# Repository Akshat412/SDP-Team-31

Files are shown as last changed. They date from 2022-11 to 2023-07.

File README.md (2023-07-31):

# SDP-Team-31
SDP23 Project for Team 31

We present SMH, a smart biking helmet and associated sensing system which can sense riders’ vital signs such as heart rate, ambient temperature and humidity, and make it accessible to them while they bike. In the event of an accident, the system would send a remote alert to a registered contact, including the rider’s location. The helmet uses a microcontroller for sampling a MEMS accelerometer capable of measuring upto 200 Gs of acceleration at 4 KHz for collision detection. In the event of a dangerous collision, the system communicates with an Android app over Bluetooth Low Energy, which then sends a text message to an emergency contact. The bike board samples temperature, humidity, heart rate, altitude and UV-index and displays them to the biker during their bike ride. Both devices are lightweight, inexpensive, and have long battery lives. 

Members: 
Marloon Paula Gonzalez - EE 2023; 
Max Morel - EE 2023; 
Ruchit Patel - EE 2023; 
Akshat Sahay - CompE 2023; 

This repository contains the hardware and software for the helmet board which performs concussion detection and generates BLE alerts for the associated smartphone app in case of a dangerous collision. Software is written using the RP2040 core in Arduino, with the Adafruit BLE Friend library to interface with the BLE module. The hardware is designed in KiCad 7.

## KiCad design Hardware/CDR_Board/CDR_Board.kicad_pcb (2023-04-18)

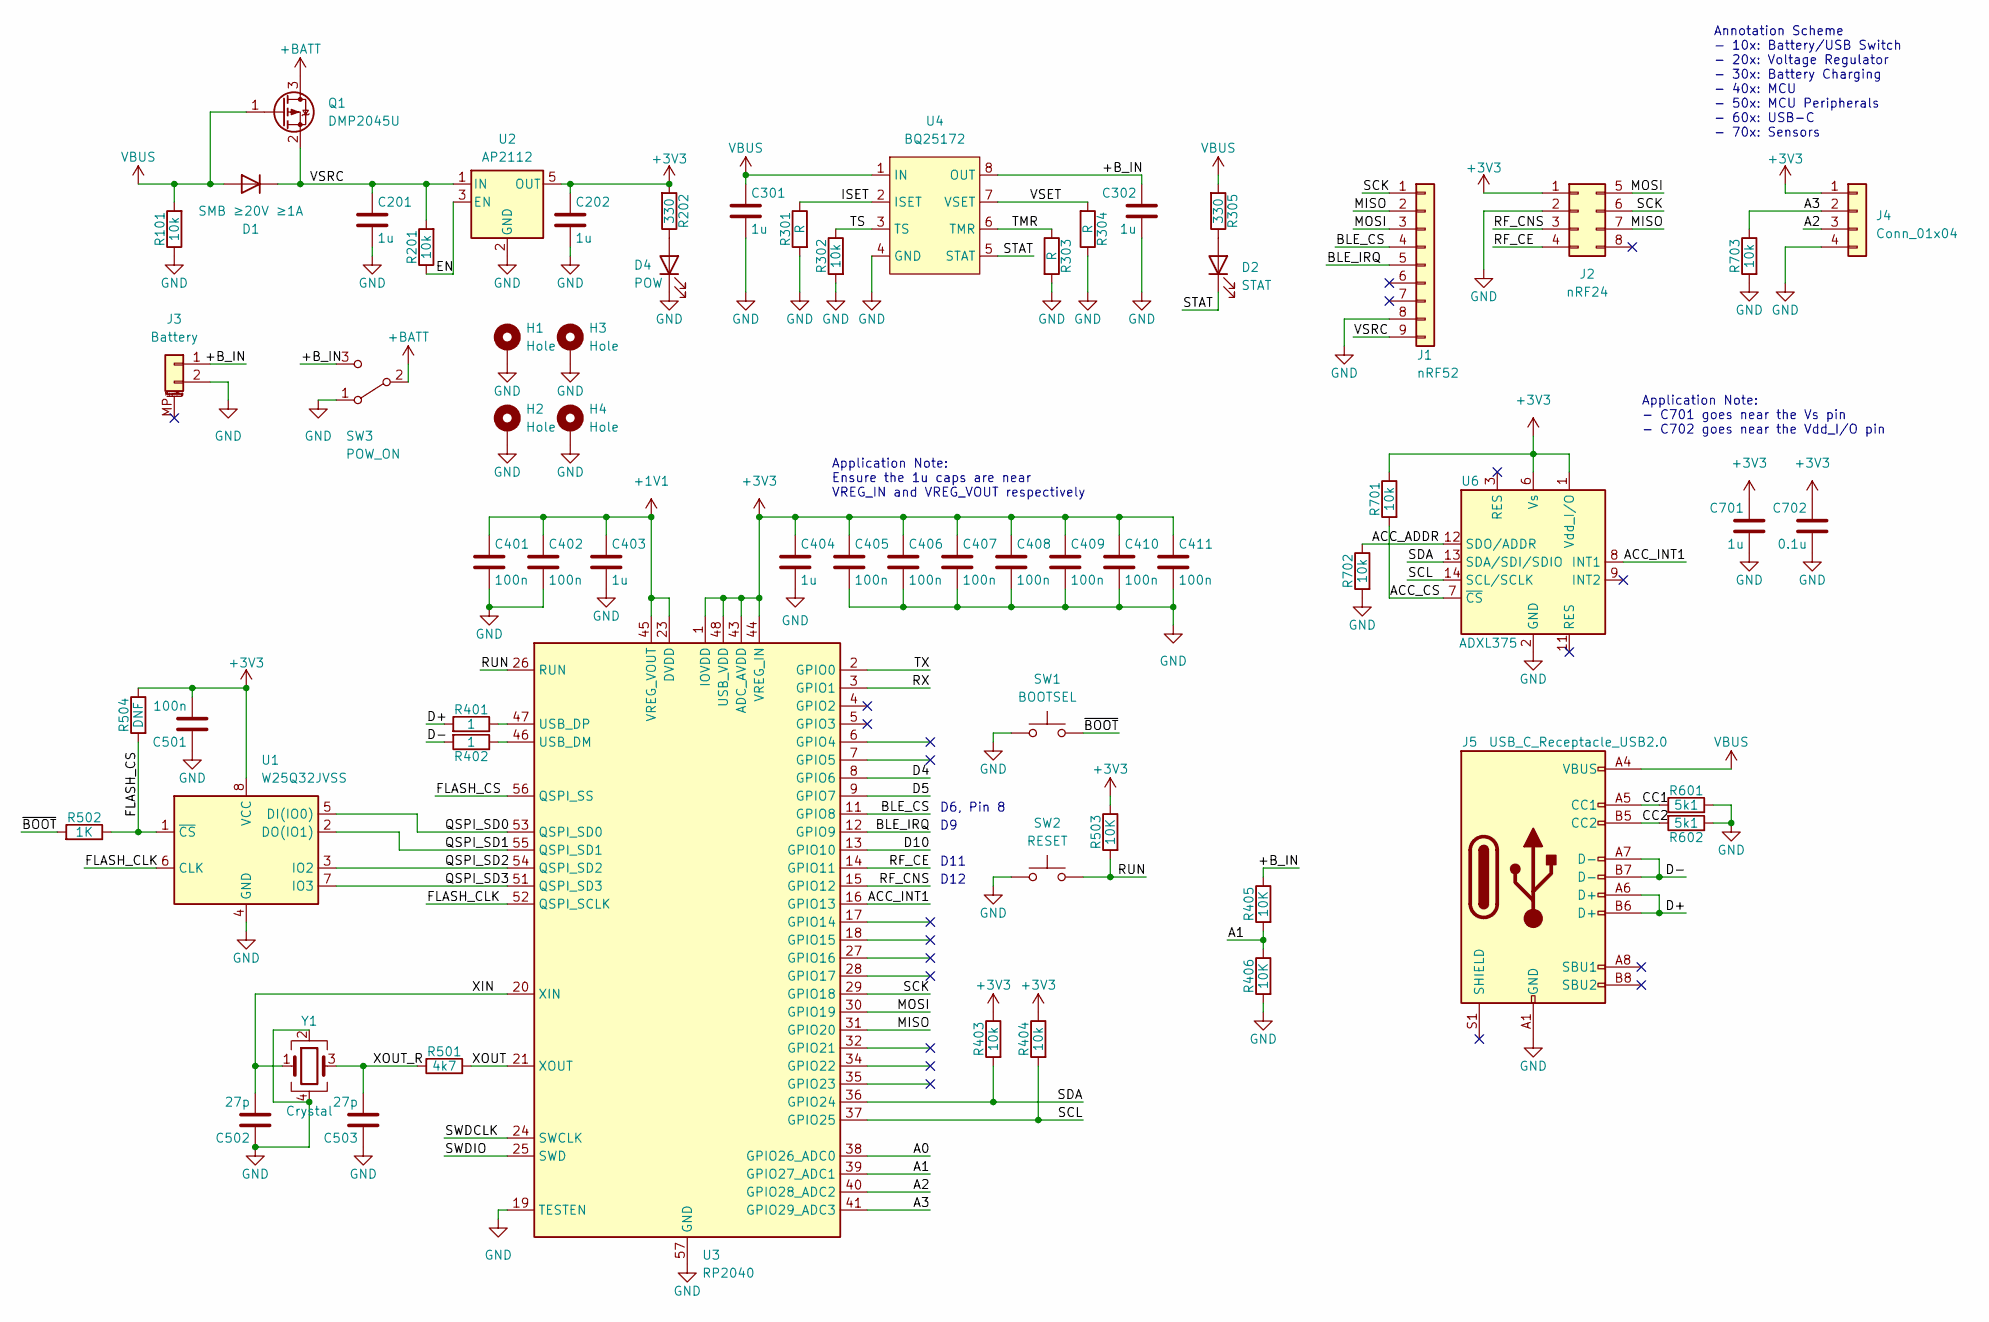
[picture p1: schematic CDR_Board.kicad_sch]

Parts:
C201, C202, C301, C302, C701: 1u; C_0805_2012Metric_Pad1.18x1.45mm_HandSolder
C401, C402, C405, C406, C407, C408, C409, C410, C411: 100n; C_0603_1608Metric_Pad1.08x0.95mm_HandSolder
C403, C404: 1u; C_0603_1608Metric_Pad1.08x0.95mm_HandSolder
C501: 100n; C_0805_2012Metric_Pad1.18x1.45mm_HandSolder
C502, C503: 27p; C_0805_2012Metric_Pad1.18x1.45mm_HandSolder
C702: 0.1u; C_0805_2012Metric_Pad1.18x1.45mm_HandSolder
D1: SMB ≥20V ≥1A; D_SOD-323_HandSoldering
D2: STAT; LED_0805_2012Metric_Pad1.15x1.40mm_HandSolder
D4: POW; LED_0805_2012Metric_Pad1.15x1.40mm_HandSolder
H1, H2, H3, H4: Hole; MountingHole_2.2mm_M2_DIN965_Pad
J1: nRF52; PinSocket_1x09_P2.54mm_Vertical
J2: nRF24; PinSocket_2x04_P2.54mm_Vertical
J3: Battery; JST_PH_S2B-PH-SM4-TB_1x02-1MP_P2.00mm_Horizontal
J4: Conn_01x04; PinSocket_1x04_P2.54mm_Vertical
J5: USB_C_Receptacle_USB2.0; USB_C_Receptacle_Palconn_UTC16-G
Q1: DMP2045U; SOT-23
R101, R201, R302, R403, R404, R701, R702, R703: 10k; R_0805_2012Metric_Pad1.20x1.40mm_HandSolder
R202, R305: 330; R_0805_2012Metric_Pad1.20x1.40mm_HandSolder
R301, R303, R304: R; R_0805_2012Metric_Pad1.20x1.40mm_HandSolder
R401, R402: 1; R_0805_2012Metric_Pad1.20x1.40mm_HandSolder
R405, R406, R503: 10K; R_0805_2012Metric_Pad1.20x1.40mm_HandSolder
R501: 4k7; R_0805_2012Metric_Pad1.20x1.40mm_HandSolder
R502: 1K; R_0805_2012Metric_Pad1.20x1.40mm_HandSolder
R504: DNF; R_0805_2012Metric_Pad1.20x1.40mm_HandSolder
R601, R602: 5k1; R_0805_2012Metric_Pad1.20x1.40mm_HandSolder
SW1: BOOTSEL; SW_Push_1P1T_NO_CK_KMR2
SW2: RESET; SW_Push_1P1T_NO_CK_KMR2
SW3: POW_ON; E-Switch-EG1218
U1: W25Q32JVSS; SOIC-8_5.23x5.23mm_P1.27mm
U2: AP2112; SOT-23-5
U3: RP2040; QFN-56-1EP_7x7mm_P0.4mm_EP3.2x3.2mm
U4: BQ25172; WSON-8-1EP_2x2mm_P0.5mm_EP0.9x1.6mm_ThermalVias
U6: ADXL375; LGA-14_3x5mm_P0.8mm_LayoutBorder1x6y
Y1: Crystal; Crystal_SMD_SeikoEpson_FA238-4Pin_3.2x2.5mm

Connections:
+1V1: C401.1, C402.1, C403.1, U3.23 (DVDD), U3.45 (VREG_VOUT), U3.50 (DVDD)
+3V3: C202.1, C404.1, C405.1, C406.1, C407.1, C408.1, C409.1, C410.1, C411.1, C501.2, C701.1, C702.1, J2.1, J4.1, R202.2, R403.1, R404.1, R503.1, R504.1, R701.1, U1.8 (VCC), U2.5 (OUT), U3.1 (IOVDD), U3.10 (IOVDD), U3.22 (IOVDD), U3.33 (IOVDD), U3.42 (IOVDD), U3.43 (ADC_AVDD), U3.44 (VREG_IN), U3.48 (USB_VDD), U3.49 (IOVDD), U6.1 (Vdd_I/O), U6.6 (Vs)
+BATT: Q1.3 (D), SW3.2 (B)
/+B_IN: C302.1, J3.1, R405.1, SW3.3 (C), U4.8 (OUT)
/A0: U3.38 (GPIO26_ADC0)
/A1: R405.2, R406.1, U3.39 (GPIO27_ADC1)
/A2: J4.3, U3.40 (GPIO28_ADC2)
/A3: J4.2, R703.1, U3.41 (GPIO29_ADC3)
/ACC_ADDR: R702.1, U6.12 (SDO/ADDR)
/ACC_CS: R701.2, U6.7 (~CS)
/ACC_INT1: U3.16 (GPIO13), U6.8 (INT1)
/BLE_CS: J1.4, U3.11 (GPIO8)
/BLE_IRQ: J1.5, U3.12 (GPIO9)
/CC1: J5.A5 (CC1), R601.2
/CC2: J5.B5 (CC2), R602.2
/D4: U3.8 (GPIO6)
/D5: U3.9 (GPIO7)
/D10: U3.13 (GPIO10)
/D+: J5.A6 (D+), J5.B6 (D+), R401.2
/D-: J5.A7 (D-), J5.B7 (D-), R402.2
/EN: R201.1, U2.3 (EN)
/FLASH_CLK: U1.6 (CLK), U3.52 (QSPI_SCLK)
/FLASH_CS: R502.1, R504.2, U1.1 (~CS), U3.56 (QSPI_SS)
/ISET: R301.1, U4.2 (ISET)
/MISO: J1.2, J2.7, U3.31 (GPIO20)
/MOSI: J1.3, J2.5, U3.30 (GPIO19)
/QSPI_SD0: U1.5 (DI(IO0)), U3.53 (QSPI_SD0)
/QSPI_SD1: U1.2 (DO(IO1)), U3.55 (QSPI_SD1)
/QSPI_SD2: U1.3 (IO2), U3.54 (QSPI_SD2)
/QSPI_SD3: U1.7 (IO3), U3.51 (QSPI_SD3)
/RF_CE: J2.4, U3.14 (GPIO11)
/RF_CNS: J2.3, U3.15 (GPIO12)
/RUN: R503.2, SW2.2, U3.26 (RUN)
/RX: U3.3 (GPIO1)
/SCK: J1.1, J2.6, U3.29 (GPIO18)
/SCL: R404.2, U3.37 (GPIO25), U6.14 (SCL/SCLK)
/SDA: R403.2, U3.36 (GPIO24), U6.13 (SDA/SDI/SDIO)
/STAT: D2.1 (K), U4.5 (STAT)
/SWDCLK: U3.24 (SWCLK)
/SWDIO: U3.25 (SWD)
/TMR: R303.1, U4.6 (TMR)
/TS: R302.1, U4.3 (TS)
/TX: U3.2 (GPIO0)
/VSET: R304.2, U4.7 (VSET)
/VSRC: C201.1, D1.1 (K), J1.9, Q1.2 (S), R201.2, U2.1 (IN)
/XIN: C502.2, U3.20 (XIN), Y1.1
/XOUT: R501.2, U3.21 (XOUT)
/XOUT_R: C503.2, R501.1, Y1.3
/~BOOT: R502.2, SW1.2
GND: C201.2, C202.2, C301.2, C302.2, C401.2, C402.2, C403.2, C404.2, C405.2, C406.2, C407.2, C408.2, C409.2, C410.2, C411.2, C501.1, C502.1, C503.1, C701.2, C702.2, D4.1 (K), H1.1, H2.1, H3.1, H4.1, J1.8, J2.2, J3.2, J4.4, J5.A1 (GND), J5.A12 (GND), J5.B1 (GND), J5.B12 (GND), R101.1, R301.2, R302.2, R303.2, R304.1, R406.2, R601.1, R602.1, R702.2, R703.2, SW1.1, SW2.1, SW3.1 (A), U1.4 (GND), U2.2 (GND), U3.19 (TESTEN), U3.57 (GND), U4.4 (GND), U6.2 (GND), U6.4 (GND), U6.5 (GND), Y1.2, Y1.4
unnamed: D2.2 (A), R305.1
unnamed: D4.2 (A), R202.1
unnamed: R402.1, U3.46 (USB_DM)
unnamed: R401.1, U3.47 (USB_DP)
VBUS: C301.1, D1.2 (A), J5.A4 (VBUS), J5.A9 (VBUS), J5.B4 (VBUS), J5.B9 (VBUS), Q1.1 (G), R101.2, R305.2, U4.1 (IN)

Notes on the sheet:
D6, Pin 8
Annotation Scheme - 10x: Battery/USB Switch - 20x: Voltage Regulator - 30x: Battery Charging - 40x: MCU - 50x: MCU Peripherals - 60x: USB-C - 70x: Sensors
Application Note: Ensure the 1u caps are near VREG_IN and VREG_VOUT respectively
D11
Application Note: - C701 goes near the Vs pin - C702 goes near the Vdd_I/O pin
D12

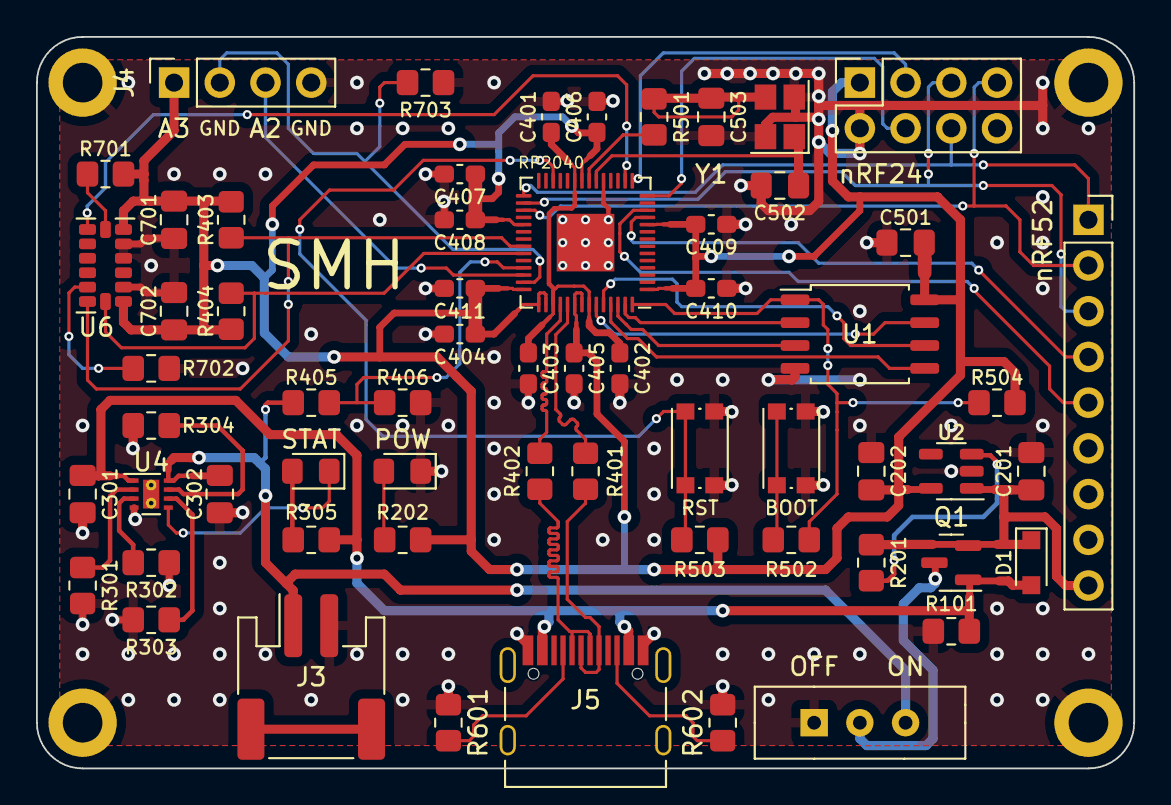
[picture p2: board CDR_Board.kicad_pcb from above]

Board: 2 copper layers, 61.0 x 40.6 mm, 65 parts (0 on the bottom side), 47 nets.

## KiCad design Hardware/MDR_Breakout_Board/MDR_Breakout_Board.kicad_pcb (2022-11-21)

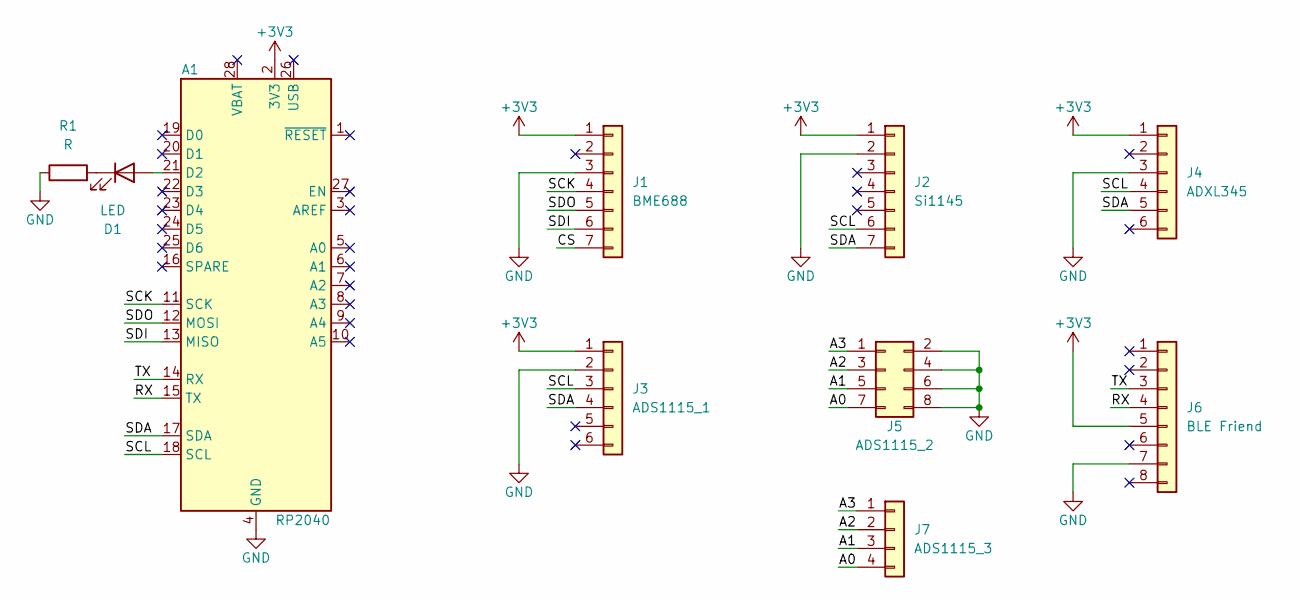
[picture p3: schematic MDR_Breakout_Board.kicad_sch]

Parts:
A1: RP2040; Adafruit_Feather
D1: LED; LED_D5.0mm
J1: BME688; PinSocket_1x07_P2.54mm_Vertical
J2: Si1145; PinSocket_1x07_P2.54mm_Vertical
J3: ADS1115_1; PinSocket_1x06_P2.54mm_Vertical
J4: ADXL345; PinSocket_1x06_P2.54mm_Vertical
J5: ADS1115_2; PinSocket_2x04_P2.54mm_Vertical
J6: BLE Friend; PinSocket_1x08_P2.54mm_Vertical
J7: ADS1115_3; PinSocket_1x04_P2.54mm_Vertical
R1: R; R_Axial_DIN0309_L9.0mm_D3.2mm_P12.70mm_Horizontal

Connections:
+3V3: A1.2 (3V3), J1.1, J2.1, J3.1, J4.1, J6.5
/A0: J5.7, J7.4
/A1: J5.5, J7.3
/A2: J5.3, J7.2
/A3: J5.1, J7.1
/CS: J1.7
/RX: A1.15 (TX), J6.4
/SCK: A1.11 (SCK), J1.4
/SCL: A1.18 (SCL), J2.6, J3.3, J4.4
/SDA: A1.17 (SDA), J2.7, J3.4, J4.5
/SDI: A1.13 (MISO), J1.6
/SDO: A1.12 (MOSI), J1.5
/TX: A1.14 (RX), J6.3
GND: A1.4 (GND), J1.3, J2.2, J3.2, J4.3, J5.2, J5.4, J5.6, J5.8, J6.7, R1.1
unnamed: A1.21 (D2), D1.2 (A)
unnamed: D1.1 (K), R1.2

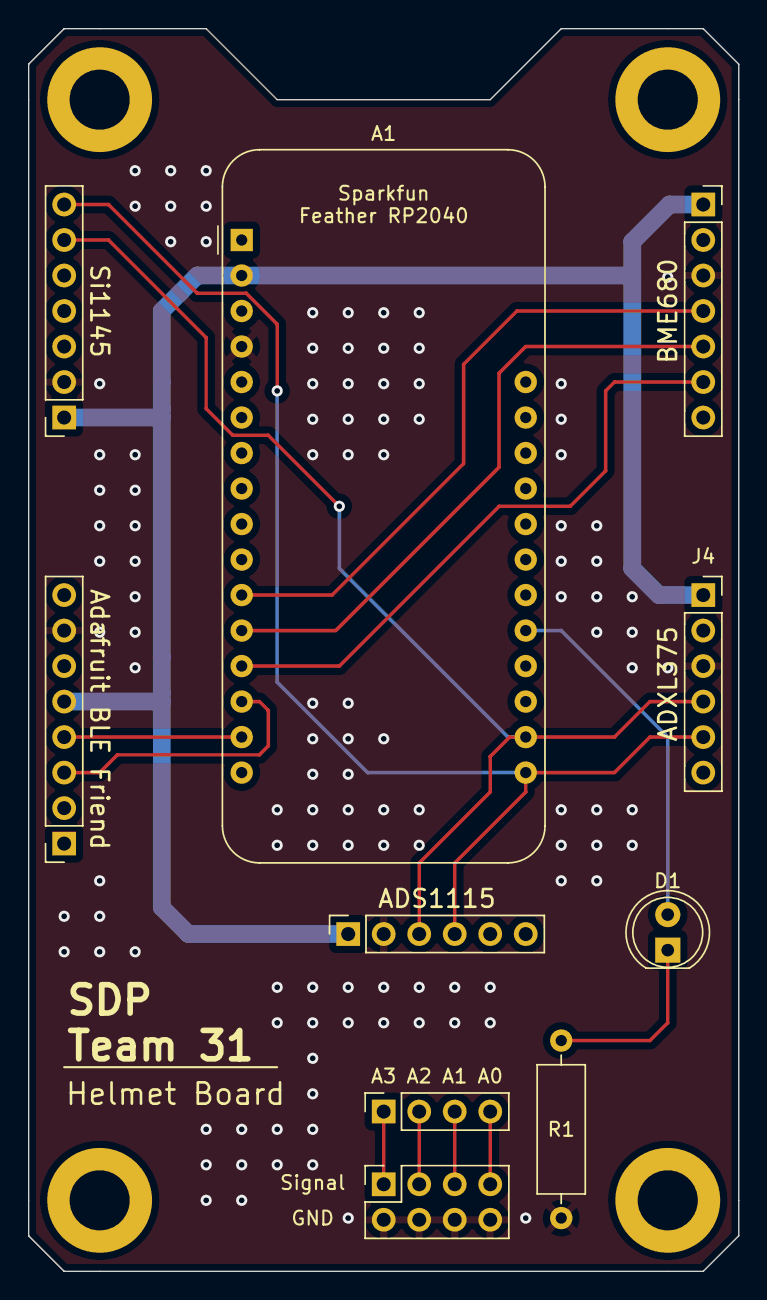
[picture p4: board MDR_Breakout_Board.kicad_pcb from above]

Board: 2 copper layers, 50.8 x 88.9 mm, 10 parts (0 on the bottom side), 15 nets.

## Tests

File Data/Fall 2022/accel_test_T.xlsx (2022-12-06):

T | M
1923 | 1.04 | 0
1926 | 0.98 | 0
1928 | 1.08 | 0
1931 | 1.16 | 0
1933 | 1.12 | 0
1935 | 0.96 | 0
1937 | 0.95 | 0
1939 | 0.9 | 0
1941 | 1.24 | 0
1943 | 0.93 | 0
1946 | 0.89 | 0
1948 | 1.16 | 0
1950 | 1.04 | 0
1952 | 0.91 | 0
1955 | 0.88 | 0
1957 | 0.89 | 0
1959 | 0.9 | 0
1961 | 0.89 | 0
1963 | 1.04 | 0
1966 | 0.9 | 0
1968 | 0.71 | 0
1970 | 1.22 | 0
1972 | 1.06 | 0
1974 | 1.03 | 0
1976 | 0.96 | 0
1979 | 1.22 | 0
1981 | 1.3 | 0
1983 | 0.71 | 0
1985 | 1.29 | 0
1987 | 1.32 | 0
1990 | 0.96 | 0
1992 | 1.11 | 0
1994 | 0.8 | 0
1996 | 1.12 | 0
1999 | 1.01 | 0
2001 | 1.06 | 0
2003 | 1 | 0
2005 | 1.01 | 0
2007 | 1.08 | 0
2010 | 0.98 | 0
2012 | 1.28 | 0
2014 | 1.14 | 0
2016 | 0.81 | 0
2018 | 1.06 | 0
2021 | 0.72 | 0
2023 | 0.79 | 0
2025 | 1.12 | 0
2027 | 1.1 | 0
2029 | 1.11 | 0
2032 | 1.21 | 0
2034 | 1 | 0
2036 | 1.08 | 0
2038 | 1.1 | 0
2040 | 1 | 0
2042 | 1.33 | 0
2045 | 1.01 | 0
2047 | 1.35 | 0
2049 | 0.86 | 0
2051 | 0.91 | 0
2053 | 0.81 | 0
2055 | 1 | 0
2057 | 1.1 | 0
2060 | 1.06 | 0
2062 | 1.04 | 0
2064 | 1 | 0
2066 | 0.93 | 0
2068 | 1.23 | 0
2071 | 0.99 | 0
2073 | 0.93 | 0
2075 | 1.2 | 0
2077 | 0.84 | 0
2079 | 1.12 | 0
2082 | 0.78 | 0
2084 | 0.89 | 0
2086 | 1.25 | 0
2088 | 0.98 | 0
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

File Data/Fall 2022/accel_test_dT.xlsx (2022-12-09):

=~=~=~=~=~=~=~=~=~=~=~= PuTTY log 2022.12.05 17:56:13 =~=~=~=~=~=~=~=~=~=~=~=
ADXL375 Accelerometer Test
dT
2.179721816
dT | M | C
2 | 1.09 | 0
3 | 0.95 | 0
2 | 1.01 | 0
2 | 1.12 | 0
2 | 1.13 | 0
2 | 1.32 | 0
3 | 0.93 | 0
2 | 0.81 | 0
2 | 1.5 | 0
2 | 1.02 | 0
2 | 0.98 | 0
2 | 1.08 | 0
2 | 1 | 0
2 | 0.81 | 0
2 | 1 | 0
3 | 1.31 | 0
2 | 1.1 | 0
2 | 0.88 | 0
2 | 1.25 | 0
2 | 1.24 | 0
3 | 0.72 | 0
2 | 0.9 | 0
2 | 1 | 0
2 | 0.97 | 0
2 | 0.99 | 0
3 | 1.24 | 0
2 | 1.04 | 0
2 | 0.98 | 0
2 | 0.9 | 0
2 | 1.12 | 0
2 | 1.07 | 0
2 | 1.19 | 0
2 | 1.32 | 0
2 | 1.23 | 0
3 | 1.27 | 0
2 | 1.23 | 0
2 | 1.1 | 0
2 | 0.93 | 0
2 | 0.89 | 0
3 | 1.28 | 0
2 | 1 | 0
2 | 0.91 | 0
2 | 1.28 | 0
2 | 1.3 | 0
2 | 1.06 | 0
2 | 1.12 | 0
2 | 1.24 | 0
2 | 1.12 | 0
3 | 1.08 | 0
2 | 1 | 0
2 | 1.03 | 0
2 | 1.28 | 0
3 | 1.06 | 0
2 | 1.18 | 0
2 | 1.36 | 0
2 | 1.13 | 0
2 | 1.18 | 0
3 | 0.79 | 0
2 | 1.18 | 0
2 | 1.1 | 0
2 | 1.13 | 0
2 | 1.04 | 0
2 | 1.18 | 0
3 | 1.22 | 0
2 | 1.13 | 0
2 | 1.4 | 0
2 | 0.97 | 0
2 | 1.27 | 0
3 | 1.18 | 0
2 | 1.05 | 0
2 | 1.03 | 0
2 | 1.09 | 0
2 | 1.24 | 0
3 | 1 | 0
2 | 1.02 | 0
2 | 1.19 | 0
2 | 1.11 | 0
2 | 1.35 | 0
3 | 1.18 | 0
2 | 1.09 | 0
2 | 0.89 | 0
2 | 1.16 | 0
3 | 0.95 | 0
2 | 1.27 | 0
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

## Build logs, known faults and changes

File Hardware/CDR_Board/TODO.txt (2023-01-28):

TODO:
	- Choose LDO IC 
		- 200 mA 3.3V, as efficient as possible
		- Choose passive values accordingly 
	- Design NiMH charging circuit
		- Datasheet has calculations
		- Choose passive values accordingly
		- Find appropriate NiMH batteries

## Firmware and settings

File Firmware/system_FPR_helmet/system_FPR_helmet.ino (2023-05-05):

/*
 * SDP23 Team 31
 * FPR System Software - Helmet 
 * --------------------
 * Samples accelerometer
 * If collision, goes into alert state
 * Remote alert over BLE to Android app 
 * Device mode:   switch between FSR and collisions  
 * System checks: LED turns on if peripherals connected 
 * System alerts: BUZZER if peripheral disconnected during operation 
 */

/* include statements */
#include <Wire.h>
#include <SPI.h>

#include "Adafruit_BLE.h"
#include "Adafruit_BluefruitLE_SPI.h"
#include "Adafruit_BluefruitLE_UART.h"

#include "BluefruitConfig.h"

/* hardware and const defines */
#define ADXL375 0x53
#define FSR     A3 
#define BUZZER  A2        
#define BATT    A1
#define LED     11

#define ADXL375_MG2G_MULTIPLIER (0.049) // 49mg per lsb
#define ADXL375_DEV_ID 0xE5             // accelerometer device ID 
#define FACTORYRESET_ENABLE 1           // reference in Adafruit test code 

// collision locations 
#define FRONT_RIGHT 1
#define FRONT_LEFT  2
#define BACK_RIGHT  3
#define BACK_LEFT   4

// buzzer frequencies
#define BUZZER_FSR  2000 
#define BUZZER_CD   1000
#define BUZZER_ERR  500 

/* BLE Friend over hardware SPI, using SCK/MOSI/MISO hardware SPI pins and then user selected CS/IRQ/RST */
Adafruit_BluefruitLE_SPI ble(BLUEFRUIT_SPI_CS, BLUEFRUIT_SPI_IRQ, BLUEFRUIT_SPI_RST); 

/* variables for computation */
uint8_t acc_addr = 0; // ADXL375 address

double mag = 0; // magnitude of collision

// coordinates for accelerometer 
float x = 0; 
float y = 0; 
float z = 0; 

// collision location 
double theta_impact = 0; 
uint8_t direction = 0; 

// device mode 
uint8_t dev_mode = 1; 

// FSR output 
uint16_t helm_tight = 0;

// LED state for sampling rate 
uint8_t led_state = 0; 

void setup() {
  // initialize serial at 115200
  Serial.begin(115200);

  // set SCL to 400KHz and begin I2C
  Wire.setClock(400000); 
  Wire.begin();

  // communicate to get ADXL375 address 
  Wire.beginTransmission(ADXL375);
  Wire.write(0x00); 
  Wire.endTransmission(false);

  Wire.requestFrom(ADXL375, 1, true);
  acc_addr = Wire.read();  

  // check ADXL375 return address
  if(acc_addr != ADXL375_DEV_ID) {
    while(1) {
      // print to console for debugging 
      Serial.println("ERROR: Failure communicating with ADXL375"); 

      tone(BUZZER, BUZZER_ERR);
      delay(250);
      noTone(BUZZER);
      delay(250);
    }
  }

  // communicate to set up ADXL375
  Wire.beginTransmission(ADXL375);
  Wire.write(0x2C); // write to BW_RATE register  
  Wire.write(0x0F); // set bits D3:D0 to 1101 for 800 Hz
  Wire.endTransmission();

  Wire.beginTransmission(ADXL375);
  Wire.write(0x2D); // write to POWER_CTL register 
  Wire.write(0x08); // set bit D3 high for measurement 
  Wire.endTransmission();

  Wire.beginTransmission(ADXL375);
  Wire.write(0x31); // write to DATA_FORMAT register
  Wire.write(0x0B); // set bits D4:D0 to 01011 for format
  Wire.endTransmission();

  // initialize BLE Friend 
  Serial.print(F("Initialising the Bluefruit LE module: "));
  if ( !ble.begin(VERBOSE_MODE) ) {
    while(1) {
      // print to console for debugging 
      Serial.println("ERROR: Failure communicating with BLE module"); 

      tone(BUZZER, BUZZER_ERR);
      delay(250);
      noTone(BUZZER);
      delay(250);
    } 
  }

  // factory reset to remove old characteristics 
  if ( FACTORYRESET_ENABLE ) {
    Serial.println(F("Performing a factory reset: "));
    if ( ! ble.factoryReset() ){
      while(1) {
        // print to console for debugging 
        Serial.println("ERROR: Failure resetting BLE module"); 

        tone(BUZZER, BUZZER_ERR);
        delay(250);
        noTone(BUZZER);
        delay(250);
      } 
    }
  }

  // disable echo from console 
  ble.echo(false);

  // define new service with UUID 0x180E, PHONE ALERT STATUS
  ble.println("AT+GATTADDSERVICE=UUID=0x180E");
  ble.waitForOK();  

  // define new characteristic with UUID 0x2A46, NEW ALERT
  ble.println("AT+GATTADDCHAR=UUID=0x2A46,PROPERTIES=0x02,MIN_LEN=1,VALUE=75");
  ble.waitForOK(); 

  // reset module to implement new service 
  ble.println("ATZ");
  ble.waitForOK(); 

  // GPIO enables 
  pinMode(LED, OUTPUT); 
  pinMode(BUZZER, OUTPUT); 
  pinMode(FSR, INPUT); 
  pinMode(BATT, INPUT); 

  digitalWrite(LED, HIGH); 
}

void loop() {
  if(dev_mode == 0) {
    helm_tight = analogRead(FSR); 

    if(helm_tight > 128) {
      // beep buzzer 
      tone(BUZZER, BUZZER_FSR);
      delay(250);
      noTone(BUZZER);
      delay(250); 

      tone(BUZZER, BUZZER_FSR);
      delay(250);
      noTone(BUZZER);
      delay(250); 

      tone(BUZZER, BUZZER_FSR);
      delay(250);
      noTone(BUZZER);
      delay(250); 

      // set device mode to 1
      dev_mode = 1; 
    }
  }

  else {
    // communicate to get data from ADXL375
    Wire.beginTransmission(ADXL375);
    Wire.write(0x32); 
    Wire.endTransmission(false);

    // read 6 byte over I2C, convert to normal values
    Wire.requestFrom(ADXL375, 6, true); 
    x = (int16_t)( Wire.read()| Wire.read() << 8); 
    y = (int16_t)( Wire.read()| Wire.read() << 8); 
    z = (int16_t)( Wire.read()| Wire.read() << 8); 

    // convert values to Gs 
    x = x * ADXL375_MG2G_MULTIPLIER; 
    y = y * ADXL375_MG2G_MULTIPLIER; 
    z = z * ADXL375_MG2G_MULTIPLIER; 

    // calculate magnitude 
    mag = sqrt(x*x + y*y + z*z); 

    // check magnitude for collision, 85 Gs
    if(mag > 30) {
      // collision, enter alert state
      Serial.println(mag); 

      // calculate impact location and store in characteristic 
      if(x > 0) {
        // only front right or back right 
        theta_impact = atan(y/x) * 180/3.14;

        if(theta_impact >= 0 && theta_impact <= 90) direction = FRONT_RIGHT; 
        else direction = BACK_RIGHT;
      }

      else {
        // only front left or back left 
        theta_impact = atan(y/x) * 180/3.14 + 180;

        if(theta_impact >= 90 && theta_impact <= 180) direction = FRONT_LEFT;
        else direction = BACK_LEFT;  
      }
      
      // change value of characteristic 
      ble.println("AT+GATTCHAR=1,65");
      ble.waitForOK(); 
      
      // buzzer at 1000 Hz
      while(1) {
        tone(BUZZER, 1000);
        delay(250);
        noTone(BUZZER);
        delay(250);   
      }
    }
  } 

  // system check to ensure everything is good 
  if(millis() % 600000 == 0) {
    // battery level check 
    if(analogRead(BATT) < 48) {
      // turn off system LED
      digitalWrite(LED, LOW); 

      // beep 
      tone(BUZZER, BUZZER_ERR);
      delay(250);
      noTone(BUZZER);
      delay(250); 

      tone(BUZZER, BUZZER_ERR);
      delay(250);
      noTone(BUZZER);
      delay(250); 

      tone(BUZZER, BUZZER_ERR);
      delay(250);
      noTone(BUZZER);
      delay(250); 
    }

    // communicate to get ADXL375 address 
    Wire.beginTransmission(ADXL375);
    Wire.write(0x00); 
    Wire.endTransmission(false);

    Wire.requestFrom(ADXL375, 1, true);
    acc_addr = Wire.read();  

    // check ADXL375 return address
    if(acc_addr != ADXL375_DEV_ID) {
      digitalWrite(LED, LOW); 

      while(1) {
        // print to console for debugging 
        Serial.println("ERROR: Failure communicating with ADXL375"); 

        tone(BUZZER, BUZZER_ERR);
        delay(250);
        noTone(BUZZER);
        delay(250);
      }
    }
  }

  /*
  if(led_state == 0) {
    digitalWrite(LED, HIGH); 
    led_state = 1; 
  }

  else {
    digitalWrite(LED, LOW); 
    led_state = 0; 
  }
  */
}

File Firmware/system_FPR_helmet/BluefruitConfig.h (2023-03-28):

// COMMON SETTINGS
// ----------------------------------------------------------------------------------------------
// These settings are used in both SW UART, HW UART and SPI mode
// ----------------------------------------------------------------------------------------------
#define BUFSIZE                        160    // Size of the read buffer for incoming data
#define VERBOSE_MODE                   true   // If set to 'true' enables debug output


// SOFTWARE UART SETTINGS
// ----------------------------------------------------------------------------------------------
// The following macros declare the pins that will be used for 'SW' serial.
// You should use this option if you are connecting the UART Friend to an UNO
// ----------------------------------------------------------------------------------------------
#define BLUEFRUIT_SWUART_RXD_PIN       9      // Required for software serial!
#define BLUEFRUIT_SWUART_TXD_PIN       10     // Required for software serial!
#define BLUEFRUIT_UART_CTS_PIN         11     // Required for software serial!
#define BLUEFRUIT_UART_RTS_PIN         12     // Optional, set to -1 if unused


// HARDWARE UART SETTINGS
// ----------------------------------------------------------------------------------------------
// The following macros declare the HW serial port you are using. Uncomment
// this line if you are connecting the BLE to Leonardo/Micro or Flora
// ----------------------------------------------------------------------------------------------
#ifdef Serial1    // this makes it not complain on compilation if there's no Serial1
  #define BLUEFRUIT_HWSERIAL_NAME      Serial1
#endif


// SHARED UART SETTINGS
// ----------------------------------------------------------------------------------------------
// The following sets the optional Mode pin, its recommended but not required
// ----------------------------------------------------------------------------------------------
#define BLUEFRUIT_UART_MODE_PIN        -1    // Set to -1 if unused


// SHARED SPI SETTINGS
// ----------------------------------------------------------------------------------------------
// The following macros declare the pins to use for HW and SW SPI communication.
// SCK, MISO and MOSI should be connected to the HW SPI pins on the Uno when
// using HW SPI.  This should be used with nRF51822 based Bluefruit LE modules
// that use SPI (Bluefruit LE SPI Friend).
// ----------------------------------------------------------------------------------------------
#define BLUEFRUIT_SPI_CS               8
#define BLUEFRUIT_SPI_IRQ              9
#define BLUEFRUIT_SPI_RST              -1    // Optional but recommended, set to -1 if unused

// SOFTWARE SPI SETTINGS
// ----------------------------------------------------------------------------------------------
// The following macros declare the pins to use for SW SPI communication.
// This should be used with nRF51822 based Bluefruit LE modules that use SPI
// (Bluefruit LE SPI Friend).
// ----------------------------------------------------------------------------------------------
#define BLUEFRUIT_SPI_SCK              13
#define BLUEFRUIT_SPI_MISO             12
#define BLUEFRUIT_SPI_MOSI             11

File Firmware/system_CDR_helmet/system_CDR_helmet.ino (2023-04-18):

/*
 * SDP23 Team 31
 * CDR System Software 
 * --------------------
 * Samples accelerometer
 * If collision, goes into alert state
 */

/* include statements */
#include <Wire.h>
#include <SPI.h>

#include <Adafruit_Sensor.h>
#include <Adafruit_ADXL375.h>

#include "Adafruit_BLE.h"
#include "Adafruit_BluefruitLE_SPI.h"
#include "Adafruit_BluefruitLE_UART.h"

#include "BluefruitConfig.h"

/* user defines */
#define BUZZER  10
#define SQWAVE  11

#define FACTORYRESET_ENABLE 1  // reference in Adafruit test code 

/* BLE Friend over hardware SPI, using SCK/MOSI/MISO hardware SPI pins and then user selected CS/IRQ/RST */
Adafruit_BluefruitLE_SPI ble(BLUEFRUIT_SPI_CS, BLUEFRUIT_SPI_IRQ, BLUEFRUIT_SPI_RST); 

/* Initialize accelerometer and event */
Adafruit_ADXL375 accel = Adafruit_ADXL375(12345);
sensors_event_t event;

/* whether sqwave on or off */
int sqwave_state = 0; 

/* variables for computation */
double magnitude = 0; 
float x = 0; 
float y = 0; 
float z = 0; 

/* Helper function for debugging BLE Friend */
void error(const __FlashStringHelper*err) {
  Serial.println(err);
  while (1);
}

void setup() {
  // initialize serial at 115200
  Serial.begin(115200);
  Serial.println("SDP Team 31: CDR"); 
  Serial.println("-----------------");

  // initialize the accelerometer
  if(!accel.begin())
  {
    // problem connecting to accelerometer, check connections 
    while(1) Serial.println("ERROR: No ADXL375, check wiring");
  }

  // set sampling rate of accelerometer to 800 Hz, diagnostic from test code 
  accel.setDataRate(ADXL343_DATARATE_800_HZ); 

  // initialize BLE Friend 
  Serial.print(F("Initialising the Bluefruit LE module: "));
  if ( !ble.begin(VERBOSE_MODE) ) {
    while(1) Serial.println("ERROR: No BLE module, check wiring"); 
  }

  // factory reset to remove old characteristics 
  if ( FACTORYRESET_ENABLE )
  {
    /* Perform a factory reset to make sure everything is in a known state */
    Serial.println(F("Performing a factory reset: "));
    if ( ! ble.factoryReset() ){
      error(F("Couldn't factory reset"));
    }
  }

  // disable echo from console 
  ble.echo(false);

  // define new service with UUID 0x180E
  ble.println("AT+GATTADDSERVICE=UUID=0x180E");
  ble.waitForOK();  

  // define new characteristic with UUID 0x2A46
  ble.println("AT+GATTADDCHAR=UUID=0x2A46,PROPERTIES=0x02,MIN_LEN=1,VALUE=75");
  ble.waitForOK(); 

  // reset module to implement new service 
  ble.println("ATZ");
  ble.waitForOK(); 

  // GPIO enables 
  pinMode(BUZZER, OUTPUT); 
}

void loop() {
  // get a new sensor event 
  accel.getEvent(&event);

  x = event.acceleration.x / 9.81; 
  y = event.acceleration.y / 9.81; 
  z = event.acceleration.z / 9.81; 

  // calculate magnitude of current collision
  magnitude = sqrt(x*x + y*y + z*z); 

  /*
  double theta_impact = 0; 
  if(event.acceleration.z > 0) theta_impact = atan(x/z) * 180/3.14 + 180;
  else theta_impact = atan(x/z) * 180/3.14; 

  double phi = acos(y / magnitude) - 90;
  */

  // check magnitude for collision, 85 Gs
  if(magnitude > 85) {
    // collision, enter alert state
    Serial.println(magnitude); 
    
    ble.println("AT+GATTCHAR=1,65");
    ble.waitForOK(); 
    
    // buzzer at 1000 Hz
    while(1) {
      tone(BUZZER, 1000);
      delay(250);
      noTone(BUZZER);
      delay(250);   
    }
  }
}

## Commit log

2022-10-28 Added MDR PCB files
    Added MDR PCB files, started schematic
    [MDR_Breakout_Board.kicad_pcb, MDR_Breakout_Board.kicad_sch]
2022-11-01 Added MDR Breakout PCB
    [MDR_Breakout_Board.kicad_pcb, MDR_Breakout_Board.kicad_sch]
2022-11-01 MDR PCB: Added some stitching vias
    [MDR_Breakout_Board.kicad_pcb]
2022-11-21 Updated helmet code, test CSVs
    [MDR_Breakout_Board-B_Cu.gbl, MDR_Breakout_Board-B_Mask.gbs, MDR_Breakout_Board-B_Paste.gbp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]
2022-12-06 Updated Testing Code
    Testing code for all systems
    [accel_test_T.xlsx, accel_test_dT.csv, helmetTestAngles.csv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]
2022-12-09 Finalized MDR System Software
    [CDR_Board.kicad_pcb, CDR_Board.kicad_sch, accel_test_dT.csv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]
2023-01-07 CDR Board Component Placement
    Component placement on 50 mil grid.
    [CDR_Board.kicad_pcb, CDR_Board.kicad_sch, bme688Data.xlsx]
2023-01-08 CDR Board Placement Revision
    Some things on 25 mil grid, 0603 capacitors for RP2040 decoupling.
    [CDR_Board.kicad_pcb, CDR_Board.kicad_sch]
2023-01-13 Added critical traces
    [CDR_Board.kicad_pcb, CDR_Board.kicad_sch]
2023-01-22 Finished all routing
    [CDR_Board.kicad_pcb, CDR_Board.kicad_sch]
2023-01-28 Added stitching vias
    [CDR_Board.kicad_pcb, CDR_Board.kicad_sch]
2023-02-02 Added more stitching vias
    [CDR_Board.kicad_pcb, CDR_Board.kicad_sch]
2023-02-12 Finalized PCB v1
    [CDR_Board.kicad_pcb, CDR_Board.kicad_sch]
2023-02-20 Updated helmet PCB
    [CDR_Board-B_Cu.gbl, CDR_Board-B_Mask.gbs, CDR_Board-B_Paste.gbp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]
2023-03-01 Added CDR helmet code
    [CDR_Board.kicad_pcb]
2023-03-22 Added pullup/pulldown resistors for IMU
    Added pullup resistor for CS, pulldown resistor for ADDR pin of IMU. Moved silkscreen
    [CDR_Board-B_Cu.gbl, CDR_Board-B_Mask.gbs, CDR_Board-B_Paste.gbp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]
2023-03-28 Updated bike firmware, testing
    [CDR_Board.kicad_pcb, CDR_Board.kicad_sch, accel_test_T.xlsx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]
2023-03-29 Collected collision data
    [accelerometer_test.csv, collision_test_ normal.csv, collision_test_soft.csv]
2023-04-17 Updated helmet PCB
    Added voltage divider for battery measurement, pull-down resistor for FSR measurement
    [CDR_Board.kicad_pcb, CDR_Board.kicad_sch]
2023-04-18 Updated ADXL375 I2C, helmet PCB
    [CDR_Board.kicad_pcb, CDR_Board.kicad_sch, accelerometer_test.csv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]
2023-04-24 Working I2C drivers
    [collision_test_1600_4_19.csv, collision_test_2nd_4_21.csv, collision_test_3200_4_19 .csv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]
2023-05-05 FPR System Software
    Finished software for FPR helmet
    [CDR_Board.kicad_sch, collision_test_1600_4_19.csv, collision_test_3200_4_19 .csv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]
